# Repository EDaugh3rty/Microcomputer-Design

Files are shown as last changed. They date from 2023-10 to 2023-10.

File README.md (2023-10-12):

# Microcomputer-Design
Microcomputer Design is a project where a single board computer is built. 
I selected and chose all of my different components after reading many datasheets to make the computer meet the requirements.
The PCB design came next so I had to take all of my different components and put them into Kicad to design a schematic and the board itself.
The operating system written in 68K Assembly code was made to make the computer read and write to memory, read and write to the registers, and to Load and Run an S-record.

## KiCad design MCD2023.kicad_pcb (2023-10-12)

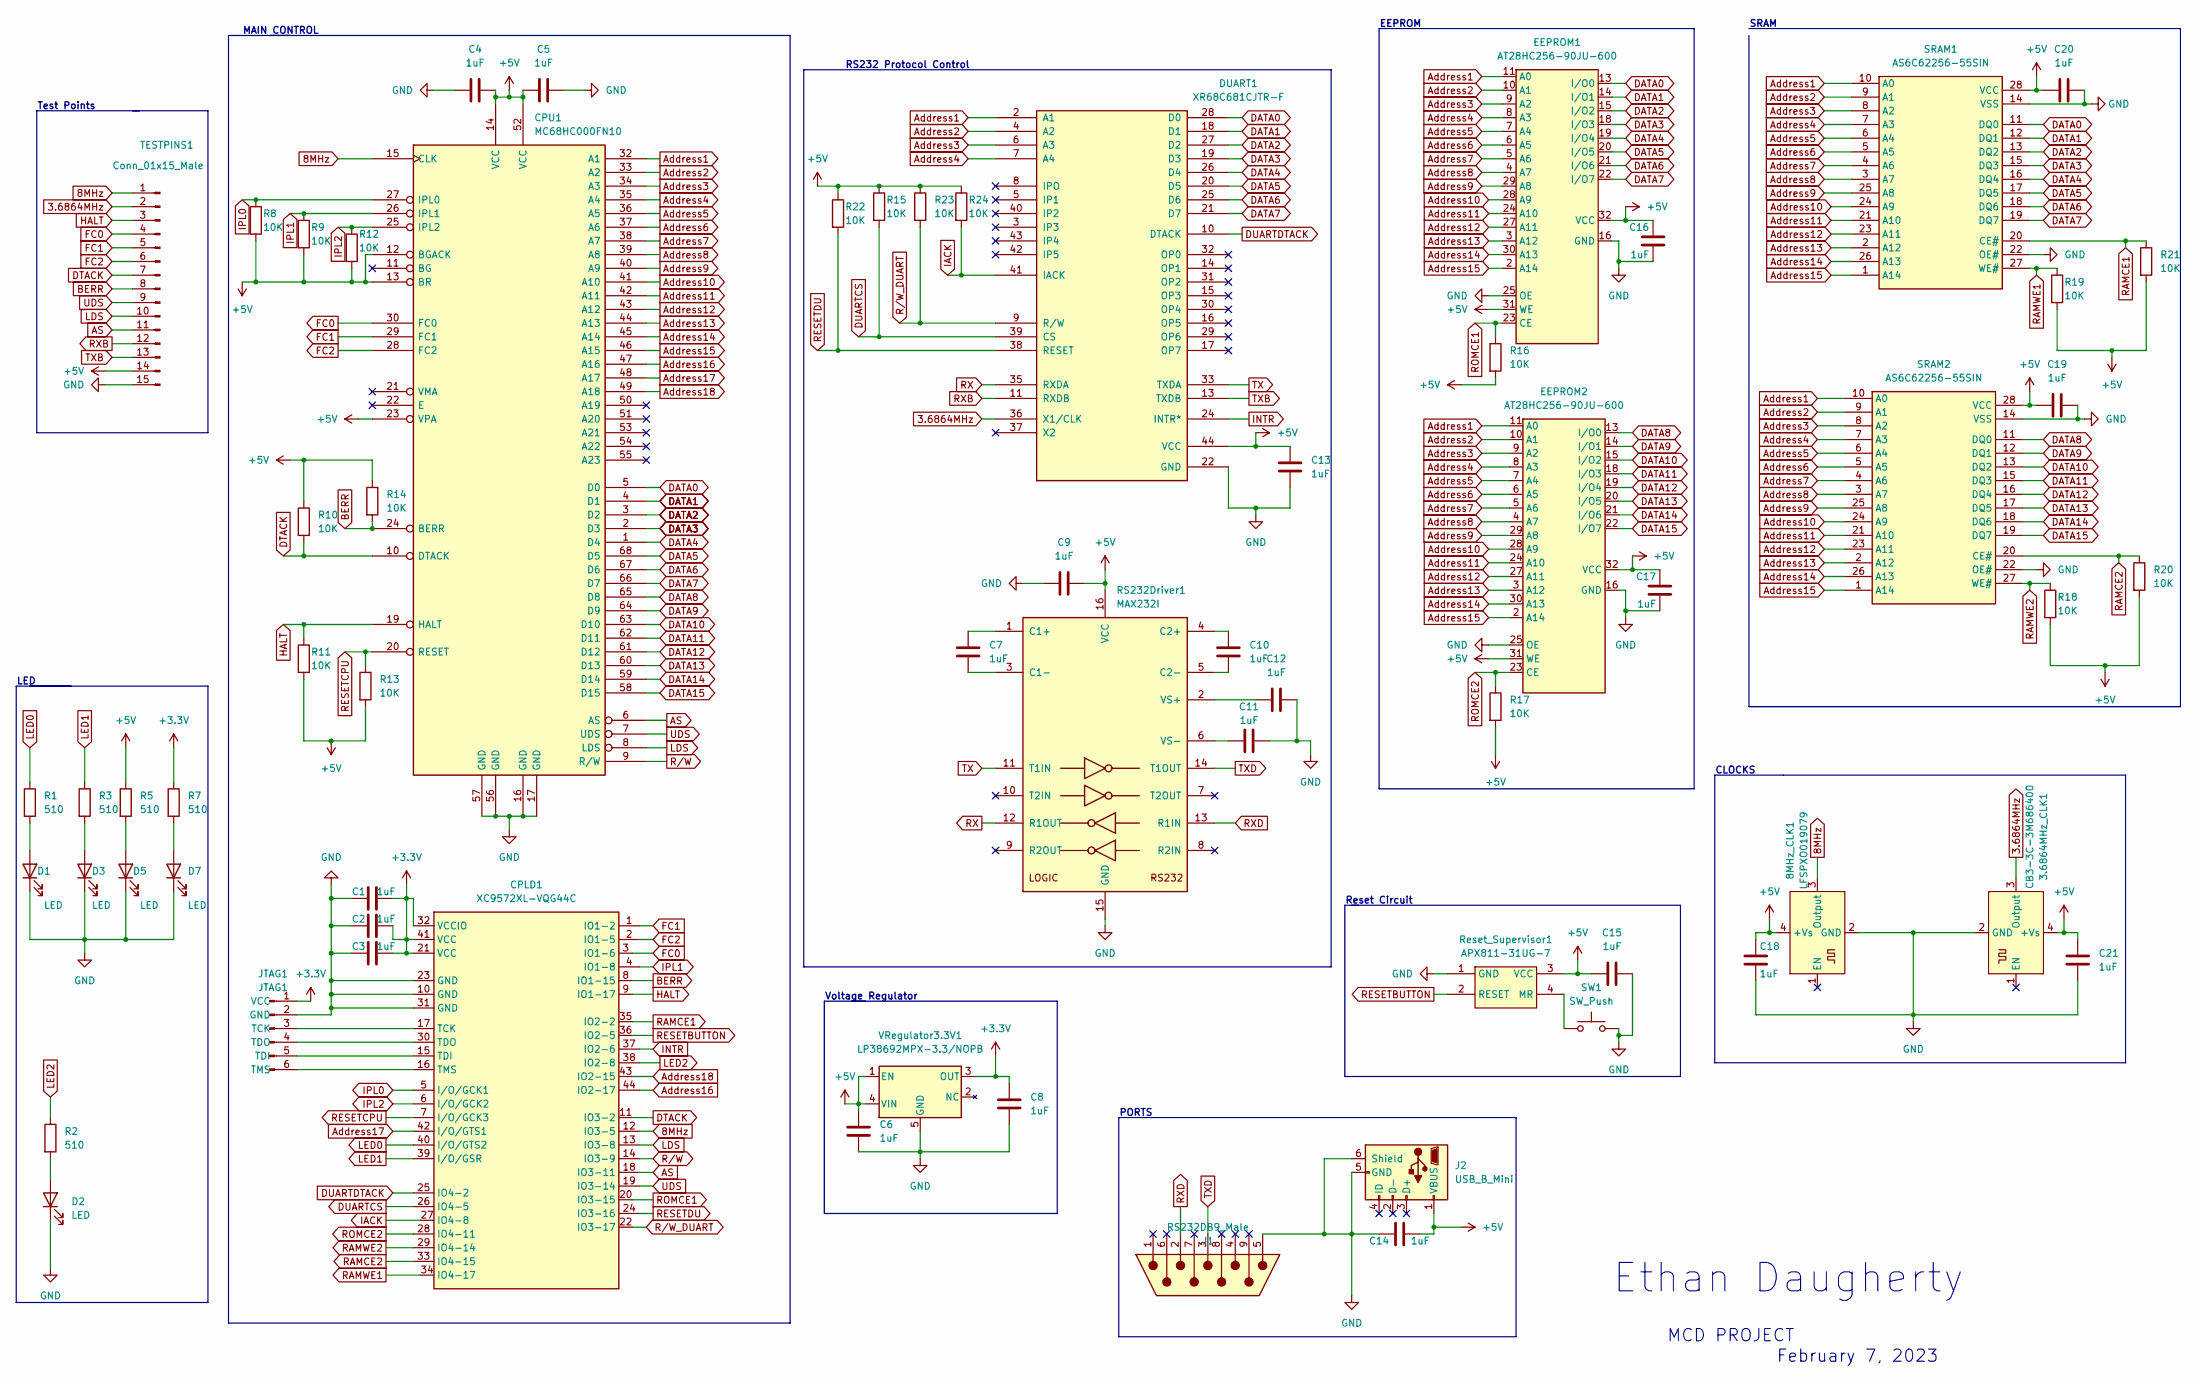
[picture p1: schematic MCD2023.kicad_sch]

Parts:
3.6864MHz_CLK1: CB3-3C-3M686400; Oscillator_SMD_IQD_IQXO70-4Pin_7.5x5.0mm
8MHz_CLK1: LFSPXO019079; Oscillator_SMD_IQD_IQXO70-4Pin_7.5x5.0mm_HandSoldering
C1, C2, C3, C4, C5, C6, C7, C8, C9, C10, C11, C12, C13, C14, C15, C16, C17, C18, C19, C20, C21: 1uF; C_0805_2012Metric_Pad1.18x1.45mm_HandSolder
CPLD1: XC9572XL-VQG44C; PLCC-44_THT-Socket
CPU1: MC68HC000FN10; PLCC-68_THT-Socket
D1, D2, D3, D5, D7: LED; LED_0805_2012Metric_Pad1.15x1.40mm_HandSolder
DUART1: XR68C681CJTR-F; PLCC-44_THT-Socket
EEPROM1, EEPROM2: AT28HC256-90JU-600; PLCC-32_THT-Socket
J1: RS232DB9_Male; DSUB-9_Male_Horizontal_P2.77x2.84mm_EdgePinOffset7.70mm_Hou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
J2: USB_B_Mini; USB_miniB_TH
JTAG1: JTAG1; JTAG
R1, R2, R3, R5, R7: 510; R_0805_2012Metric_Pad1.20x1.40mm_HandSolder
R8, R9, R10, R11, R12, R13, R14, R15, R16, R17, R18, R19, R20, R21, R22, R23, R24: 10K; R_0805_2012Metric_Pad1.20x1.40mm_HandSolder
RS232Driver1: MAX232I; SOIC-16
Reset_Supervisor1: APX811-31UG-7; SOT-143
SRAM1, SRAM2: AS6C62256-55SIN; SOP-28_V2
SW1: SW_Push; SW_SPST_B3S-1000
TESTPINS1: Conn_01x15_Male; MCD_TESTPOINTS
VRegulator3.3V1: LP38692MPX-3.3/NOPB; SOT-223-5

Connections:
3.6864MHz: 3.6864MHz_CLK1.3 (Output), DUART1.36 (X1/CLK), TESTPINS1.2
8MHz: 8MHz_CLK1.3 (Output), CPLD1.12 (IO3-5), CPU1.15 (CLK), TESTPINS1.1
+3V3: C1.2, C2.2, C3.1, C8.1, CPLD1.21 (VCC), CPLD1.32 (VCCIO), CPLD1.41 (VCC), JTAG1.1 (VCC), R7.1, VRegulator3.3V1.3 (OUT)
+5V: 3.6864MHz_CLK1.4 (+Vs), 8MHz_CLK1.4 (+Vs), C4.2, C5.1, C6.1, C9.1, C13.2, C14.2, C15.1, C16.1, C17.1, C18.1, C19.1, C20.1, C21.1, CPU1.12 (BGACK), CPU1.13 (BR), CPU1.14 (VCC), CPU1.23 (VPA), CPU1.52 (VCC), DUART1.44 (VCC), EEPROM1.31 (WE), EEPROM1.32 (VCC), EEPROM2.31 (WE), EEPROM2.32 (VCC), J2.1 (VBUS), R5.1, R8.2, R9.2, R10.1, R11.2, R12.2, R13.2, R14.1, R15.1, R16.2, R17.2, R18.2, R19.2, R20.2, R21.2, R22.1, R23.1, R24.1, RS232Driver1.16 (VCC), Reset_Supervisor1.3 (VCC), SRAM1.28 (VCC), SRAM2.28 (VCC), TESTPINS1.14, VRegulator3.3V1.1 (EN), VRegulator3.3V1.4 (VIN)
AS: CPLD1.18 (IO3-11), CPU1.6 (AS), TESTPINS1.11
Address1: CPU1.32 (A1), DUART1.2 (A1), EEPROM1.11 (A0), EEPROM2.11 (A0), SRAM1.10 (A0), SRAM2.10 (A0)
Address2: CPU1.33 (A2), DUART1.4 (A2), EEPROM1.10 (A1), EEPROM2.10 (A1), SRAM1.9 (A1), SRAM2.9 (A1)
Address3: CPU1.34 (A3), DUART1.6 (A3), EEPROM1.9 (A2), EEPROM2.9 (A2), SRAM1.8 (A2), SRAM2.8 (A2)
Address4: CPU1.35 (A4), DUART1.7 (A4), EEPROM1.8 (A3), EEPROM2.8 (A3), SRAM1.7 (A3), SRAM2.7 (A3)
Address5: CPU1.36 (A5), EEPROM1.7 (A4), EEPROM2.7 (A4), SRAM1.6 (A4), SRAM2.6 (A4)
Address6: CPU1.37 (A6), EEPROM1.6 (A5), EEPROM2.6 (A5), SRAM1.5 (A5), SRAM2.5 (A5)
Address7: CPU1.38 (A7), EEPROM1.5 (A6), EEPROM2.5 (A6), SRAM1.4 (A6), SRAM2.4 (A6)
Address8: CPU1.39 (A8), EEPROM1.4 (A7), EEPROM2.4 (A7), SRAM1.3 (A7), SRAM2.3 (A7)
Address9: CPU1.40 (A9), EEPROM1.29 (A8), EEPROM2.29 (A8), SRAM1.25 (A8), SRAM2.25 (A8)
Address10: CPU1.41 (A10), EEPROM1.28 (A9), EEPROM2.28 (A9), SRAM1.24 (A9), SRAM2.24 (A9)
Address11: CPU1.42 (A11), EEPROM1.24 (A10), EEPROM2.24 (A10), SRAM1.21 (A10), SRAM2.21 (A10)
Address12: CPU1.43 (A12), EEPROM1.27 (A11), EEPROM2.27 (A11), SRAM1.23 (A11), SRAM2.23 (A11)
Address13: CPU1.44 (A13), EEPROM1.3 (A12), EEPROM2.3 (A12), SRAM1.2 (A12), SRAM2.2 (A12)
Address14: CPU1.45 (A14), EEPROM1.30 (A13), EEPROM2.30 (A13), SRAM1.26 (A13), SRAM2.26 (A13)
Address15: CPU1.46 (A15), EEPROM1.2 (A14), EEPROM2.2 (A14), SRAM1.1 (A14), SRAM2.1 (A14)
Address16: CPLD1.44 (IO2-17), CPU1.47 (A16)
Address17: CPLD1.42 (I/O/GTS1), CPU1.48 (A17)
Address18: CPLD1.43 (IO2-15), CPU1.49 (A18)
BERR: CPLD1.8 (IO1-15), CPU1.24 (BERR), R14.2, TESTPINS1.8
DATA0: CPU1.5 (D0), DUART1.28 (D0), EEPROM1.13 (I/O0), SRAM1.11 (DQ0)
DATA1: CPU1.4 (D1), DUART1.18 (D1), EEPROM1.14 (I/O1), SRAM1.12 (DQ1)
DATA2: CPU1.3 (D2), DUART1.27 (D2), EEPROM1.15 (I/O2), SRAM1.13 (DQ2)
DATA3: CPU1.2 (D3), DUART1.19 (D3), EEPROM1.18 (I/O3), SRAM1.15 (DQ3)
DATA4: CPU1.1 (D4), DUART1.26 (D4), EEPROM1.19 (I/O4), SRAM1.16 (DQ4)
DATA5: CPU1.68 (D5), DUART1.20 (D5), EEPROM1.20 (I/O5), SRAM1.17 (DQ5)
DATA6: CPU1.67 (D6), DUART1.25 (D6), EEPROM1.21 (I/O6), SRAM1.18 (DQ6)
DATA7: CPU1.66 (D7), DUART1.21 (D7), EEPROM1.22 (I/O7), SRAM1.19 (DQ7)
DATA8: CPU1.65 (D8), EEPROM2.13 (I/O0), SRAM2.11 (DQ0)
DATA9: CPU1.64 (D9), EEPROM2.14 (I/O1), SRAM2.12 (DQ1)
DATA10: CPU1.63 (D10), EEPROM2.15 (I/O2), SRAM2.13 (DQ2)
DATA11: CPU1.62 (D11), EEPROM2.18 (I/O3), SRAM2.15 (DQ3)
DATA12: CPU1.61 (D12), EEPROM2.19 (I/O4), SRAM2.16 (DQ4)
DATA13: CPU1.60 (D13), EEPROM2.20 (I/O5), SRAM2.17 (DQ5)
DATA14: CPU1.59 (D14), EEPROM2.21 (I/O6), SRAM2.18 (DQ6)
DATA15: CPU1.58 (D15), EEPROM2.22 (I/O7), SRAM2.19 (DQ7)
DTACK: CPLD1.11 (IO3-2), CPU1.10 (DTACK), R10.2, TESTPINS1.7
DUARTCS: CPLD1.26 (IO4-5), DUART1.39 (CS), R15.2
DUARTDTACK: CPLD1.25 (IO4-2), DUART1.10 (DTACK)
FC0: CPLD1.3 (IO1-6), CPU1.30 (FC0), TESTPINS1.4
FC1: CPLD1.1 (IO1-2), CPU1.29 (FC1), TESTPINS1.5
FC2: CPLD1.2 (IO1-5), CPU1.28 (FC2), TESTPINS1.6
GND: 3.6864MHz_CLK1.2 (GND), 8MHz_CLK1.2 (GND), C1.1, C2.1, C3.2, C4.1, C5.2, C6.2, C8.2, C9.2, C11.2, C12.2, C13.1, C14.1, C15.2, C16.2, C17.2, C18.2, C19.2, C20.2, C21.2, CPLD1.10 (GND), CPLD1.23 (GND), CPLD1.31 (GND), CPU1.16 (GND), CPU1.17 (GND), CPU1.56 (GND), CPU1.57 (GND), D1.1 (K), D2.1 (K), D3.1 (K), D5.1 (K), D7.1 (K), DUART1.22 (GND), EEPROM1.16 (GND), EEPROM1.25 (OE), EEPROM2.16 (GND), EEPROM2.25 (OE), J1.0, J1.5 (GND), J2.5 (GND), J2.6 (Shield), JTAG1.2 (GND), RS232Driver1.15 (GND), Reset_Supervisor1.1 (GND), SRAM1.14 (VSS), SRAM1.22 (OE#), SRAM2.14 (VSS), SRAM2.22 (OE#), SW1.2, TESTPINS1.15, VRegulator3.3V1.5 (GND)
HALT: CPLD1.9 (IO1-17), CPU1.19 (HALT), R11.1, TESTPINS1.3
IACK: CPLD1.27 (IO4-8), DUART1.41 (IACK), R24.2
INTR: CPLD1.37 (IO2-6), DUART1.24 (INTR*)
IPL0: CPLD1.5 (I/O/GCK1), CPU1.27 (IPL0), R8.1
IPL1: CPLD1.4 (IO1-8), CPU1.26 (IPL1), R9.1
IPL2: CPLD1.6 (I/O/GCK2), CPU1.25 (IPL2), R12.1
LDS: CPLD1.13 (IO3-8), CPU1.8 (LDS), TESTPINS1.10
LED0: CPLD1.40 (I/O/GTS2), R1.1
LED1: CPLD1.39 (I/O/GSR), R3.1
LED2: CPLD1.38 (IO2-8), R2.1
unnamed: C7.1, RS232Driver1.1 (C1+)
unnamed: C7.2, RS232Driver1.3 (C1-)
unnamed: C10.1, RS232Driver1.4 (C2+)
unnamed: C10.2, RS232Driver1.5 (C2-)
unnamed: C11.1, RS232Driver1.6 (VS-)
unnamed: C12.1, RS232Driver1.2 (VS+)
unnamed: CPLD1.15 (TDI), JTAG1.5 (TDI)
unnamed: CPLD1.16 (TMS), JTAG1.6 (TMS)
unnamed: CPLD1.17 (TCK), JTAG1.3 (TCK)
unnamed: CPLD1.30 (TDO), JTAG1.4 (TDO)
unnamed: D1.2 (A), R1.2
unnamed: D2.2 (A), R2.2
unnamed: D3.2 (A), R3.2
unnamed: D5.2 (A), R5.2
unnamed: D7.2 (A), R7.2
unnamed: Reset_Supervisor1.4 (MR), SW1.1
RAMCE1: CPLD1.35 (IO2-2), R21.1, SRAM1.20 (CE#)
RAMCE2: CPLD1.33 (IO4-15), R20.1, SRAM2.20 (CE#)
RAMWE1: CPLD1.34 (IO4-17), R19.1, SRAM1.27 (WE#)
RAMWE2: CPLD1.29 (IO4-14), R18.1, SRAM2.27 (WE#)
RESETBUTTON: CPLD1.36 (IO2-5), Reset_Supervisor1.2 (RESET)
RESETCPU: CPLD1.7 (I/O/GCK3), CPU1.20 (RESET), R13.1
RESETDU: CPLD1.24 (IO3-16), DUART1.38 (RESET), R22.2
ROMCE1: CPLD1.20 (IO3-15), EEPROM1.23 (CE), R16.1
ROMCE2: CPLD1.28 (IO4-11), EEPROM2.23 (CE), R17.1
RX: DUART1.35 (RXDA), RS232Driver1.12 (R1OUT)
RXB: DUART1.11 (RXDB), TESTPINS1.12
RXD: J1.2 (RXD), RS232Driver1.13 (R1IN)
R/W: CPLD1.14 (IO3-9), CPU1.9 (R/W)
R/W_DUART: CPLD1.22 (IO3-17), DUART1.9 (R/W), R23.2
TX: DUART1.33 (TXDA), RS232Driver1.11 (T1IN)
TXB: DUART1.13 (TXDB), TESTPINS1.13
TXD: J1.3 (TXD), RS232Driver1.14 (T1OUT)
UDS: CPLD1.19 (IO3-14), CPU1.7 (UDS), TESTPINS1.9

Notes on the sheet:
EEPROM
Ethan Daugherty
Reset Circuit
Voltage Regulator
PORTS
LED
MAIN CONTROL
RS232 Protocol Control
CLOCKS
February 7, 2023
Test Points
SRAM
MCD PROJECT

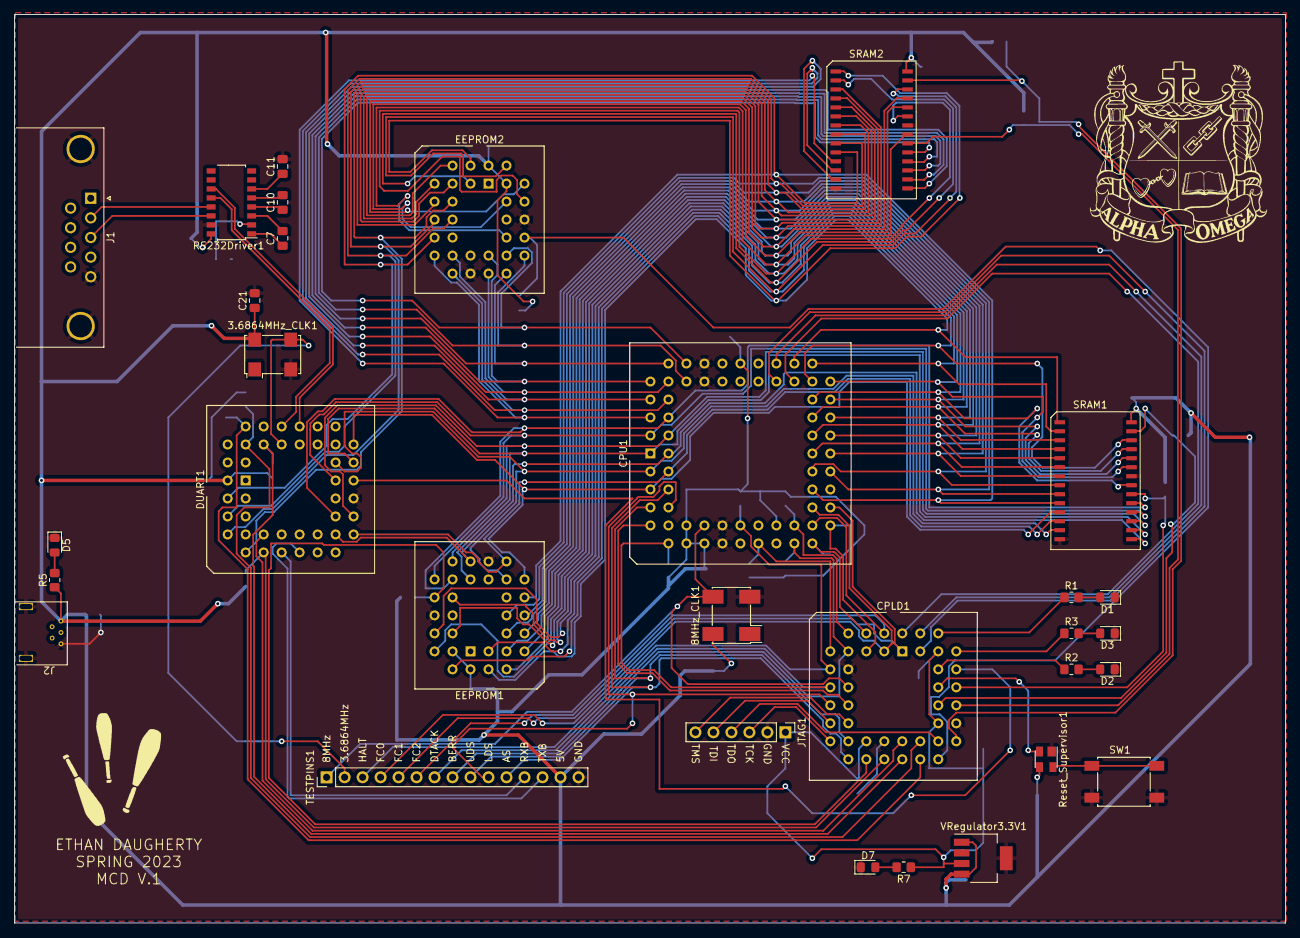
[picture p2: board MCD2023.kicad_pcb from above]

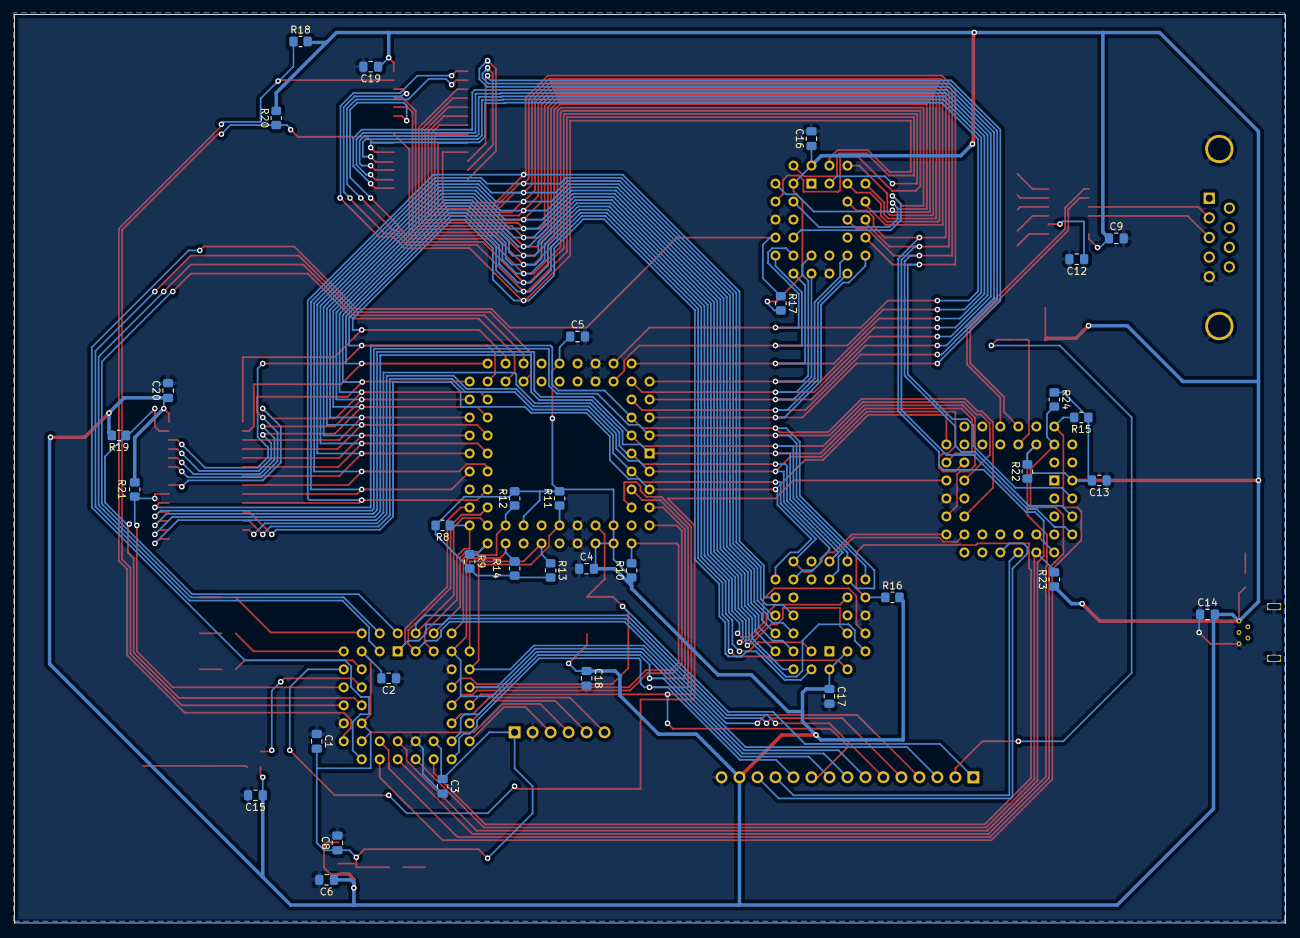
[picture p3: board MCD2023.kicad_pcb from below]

Board: 2 copper layers, 179.5 x 128.3 mm, 65 parts (34 on the bottom side), 91 nets.
